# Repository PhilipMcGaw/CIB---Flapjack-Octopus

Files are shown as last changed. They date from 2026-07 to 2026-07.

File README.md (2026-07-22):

# CIB - Flapjack Octopus
<div align="center">




<!-- removed as not used in this repo ![Fusion 360](https://badgen.net/badge/icon/FUSION%20360?icon=autodesk&label) -->

</div>

| By Ed Bowlby, NOAA/Olympic Coast NMS; NOAA/OAR/Office of Ocean Exploration - NOAA Photo Library, Public Domain (https://commons.wikimedia.org/w/index.php?curid=11244142) | Breakout board for Labjack T7 |
| --- |:---:|

Breakout board for Labjack T7

### Flapjack Octopus -- Labjack T7 Breakout

This is a breakout PCB for a Labjack T7, with 2.5 mm pitch screw headers to allow for quick wiring to the breakout PCB.

  * Digital IO ports are 5 V tolerant, there is no additional protection on the PCB.
  * Digital IO on ports C, E, F and M each have an LED that illuminates when 5V DC is applied
  * Digital IO port F is also set up as eight relay outputs, allowing up to eight 12/24 V (separate power supply required) to be driven from the T7 Labjack
  * Analogue in ports are taken via a potential divider to allow pre-scaling if required.
  * Additional terminals are available for 5V and Ground, as well as other pins, these are on the lower edge.

# Sub Modules

github.com/PhilipMcGaw/common_kicad

git submodule add https://github.com/PhilipMcGaw/common_kicad KiCAD/Common

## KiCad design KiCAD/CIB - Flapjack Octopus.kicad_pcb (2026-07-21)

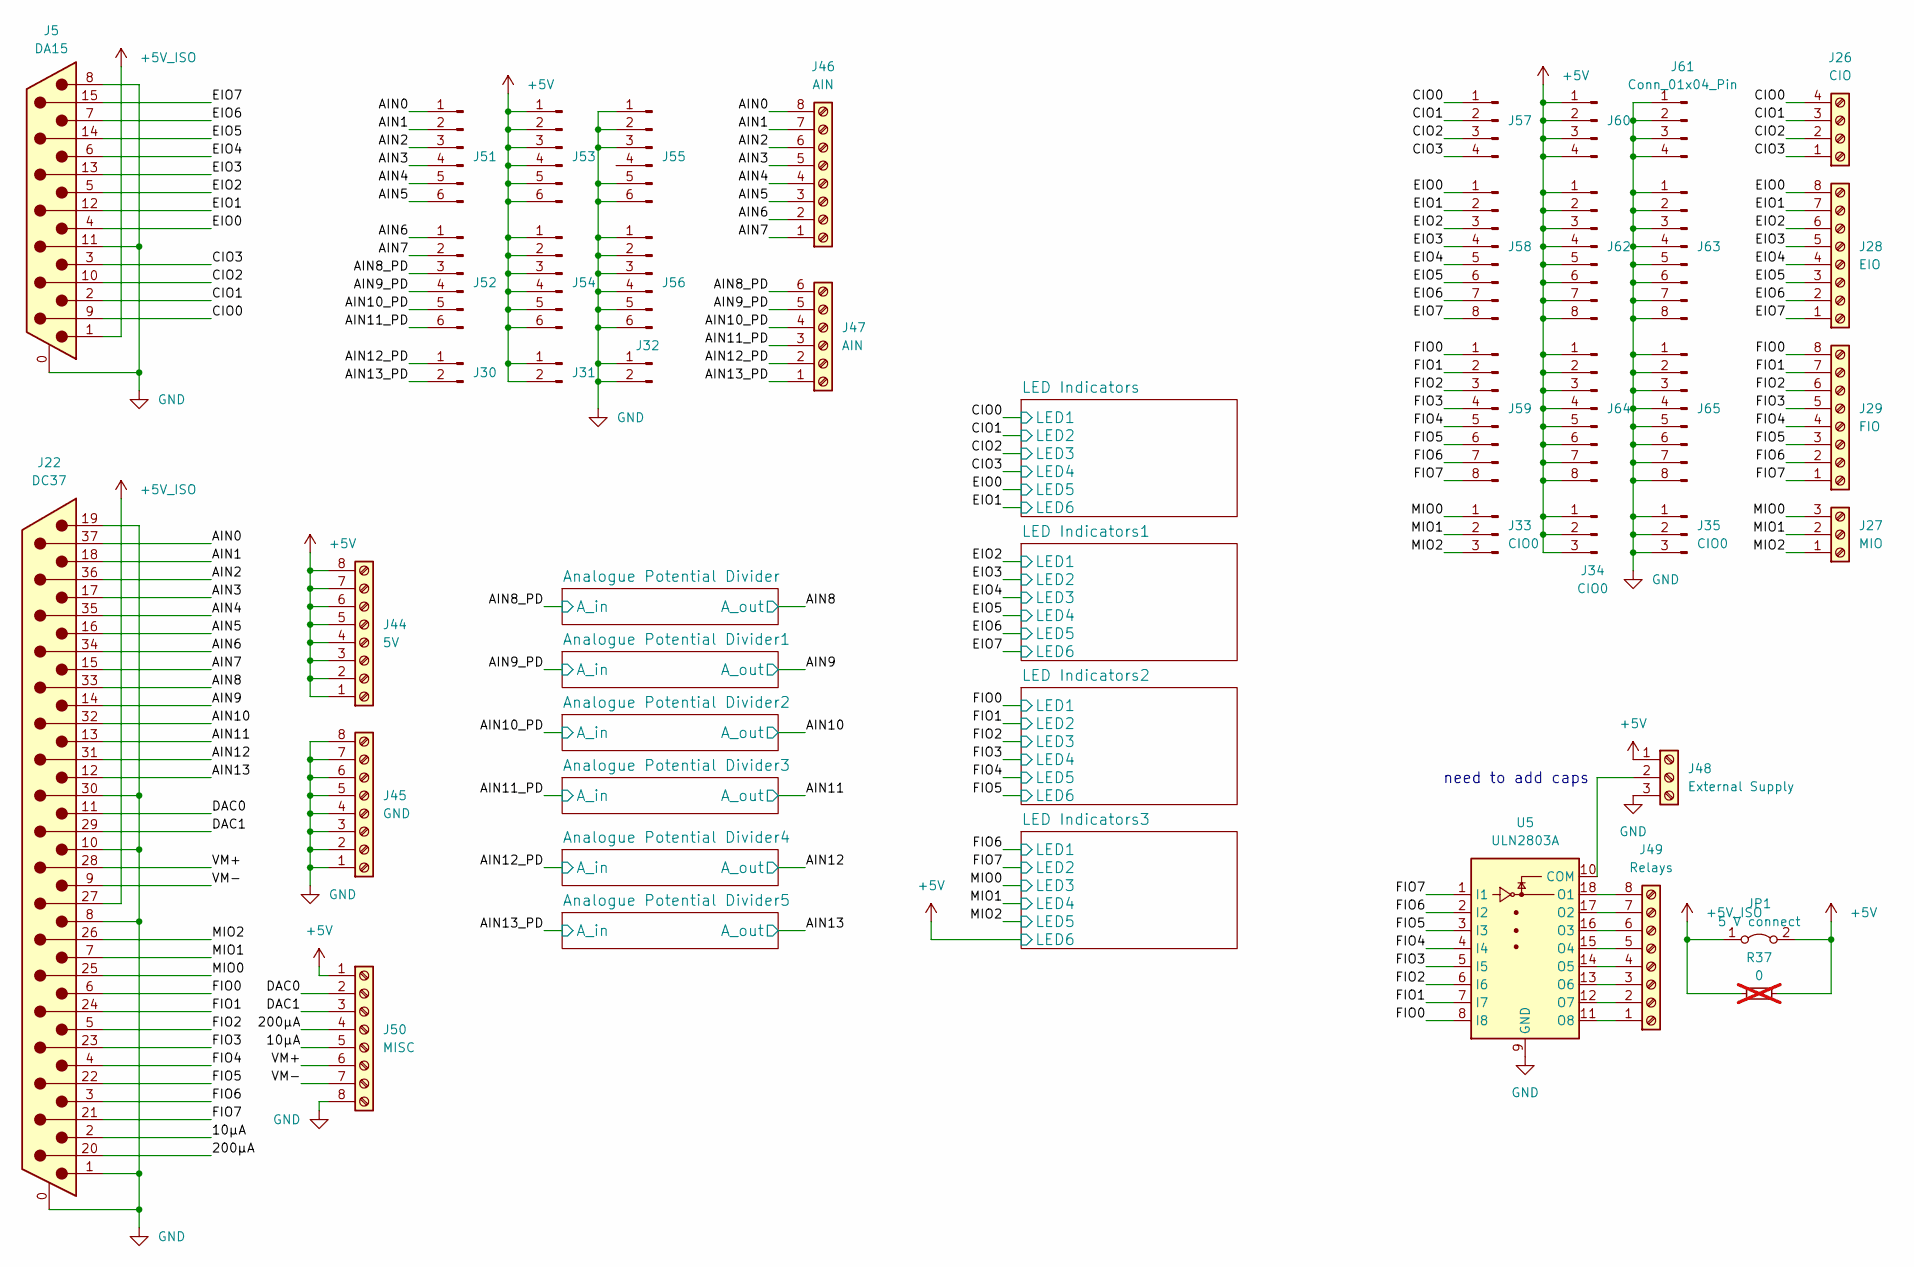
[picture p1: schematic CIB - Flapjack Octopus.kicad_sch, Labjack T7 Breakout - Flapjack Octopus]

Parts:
J5: DA15; DSUB-15_Male_Horizontal_P2.77x2.84mm_EdgePinOffset9.90mm_Ho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
J22: DC37; DSUB-37_Male_Horizontal_P2.77x2.84mm_EdgePinOffset7.70mm_Ho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
J26: CIO; TerminalBlock_Phoenix_MPT-0,5-4-2.54_1x04_P2.54mm_Horizontal
J27: MIO; TerminalBlock_Phoenix_MPT-0,5-3-2.54_1x03_P2.54mm_Horizontal
J28: EIO; TerminalBlock_Phoenix_MPT-0,5-8-2.54_1x08_P2.54mm_Horizontal
J29: FIO; TerminalBlock_Phoenix_MPT-0,5-8-2.54_1x08_P2.54mm_Horizontal
J30, J31, J32: Conn_01x02_Pin; PinSocket_1x02_P2.54mm_Vertical
J33, J34, J35: CIO0; PinSocket_1x03_P2.54mm_Vertical
J44: 5V; TerminalBlock_Phoenix_MPT-0,5-8-2.54_1x08_P2.54mm_Horizontal
J45: GND; TerminalBlock_Phoenix_MPT-0,5-8-2.54_1x08_P2.54mm_Horizontal
J46: AIN; TerminalBlock_Phoenix_MPT-0,5-8-2.54_1x08_P2.54mm_Horizontal
J47: AIN; TerminalBlock_Phoenix_MPT-0,5-6-2.54_1x06_P2.54mm_Horizontal
J48: External Supply; TerminalBlock_Phoenix_MPT-0,5-3-2.54_1x03_P2.54mm_Horizontal
J49: Relays; TerminalBlock_Phoenix_MPT-0,5-8-2.54_1x08_P2.54mm_Horizontal
J50: MISC; TerminalBlock_Phoenix_MPT-0,5-8-2.54_1x08_P2.54mm_Horizontal
J51, J52, J53, J54, J55, J56: Conn_01x06_Pin; PinHeader_1x06_P2.54mm_Vertical
J57, J60, J61: Conn_01x04_Pin; PinHeader_1x04_P2.54mm_Vertical
J58, J59, J62, J63, J64, J65: Conn_01x08_Pin; PinHeader_1x08_P2.54mm_Vertical
JP1: 5 V connect; SolderJumper-2_P1.3mm_Bridged_Pad1.0x1.5mm
R37: 0; R_0805_2012Metric_Pad1.20x1.40mm_HandSolder; not fitted
U5: ULN2803A; SOIC-18W_7.5x11.6mm_P1.27mm

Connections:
+5V: J31.1, J31.2, J34.1, J34.2, J34.3, J44.1, J44.2, J44.3, J44.4, J44.5, J44.6, J44.7, J44.8, J48.1, J50.1, J53.1, J53.2, J53.3, J53.4, J53.5, J53.6, J54.1, J54.2, J54.3, J54.4, J54.5, J54.6, J60.1, J60.2, J60.3, J60.4, J62.1, J62.2, J62.3, J62.4, J62.5, J62.6, J62.7, J62.8, J64.1, J64.2, J64.3, J64.4, J64.5, J64.6, J64.7, J64.8, JP1.2 (B), R37.2; also elsewhere on the board
+5V_ISO: J5.1, J22.27, JP1.1 (A), R37.1
/10µA: J22.2, J50.5
/200µA: J22.20, J50.4
/AIN0: J22.37, J46.8, J51.1
/AIN1: J22.18, J46.7, J51.2
/AIN2: J22.36, J46.6, J51.3
/AIN3: J22.17, J46.5, J51.4
/AIN4: J22.35, J46.4, J51.5
/AIN5: J22.16, J46.3, J51.6
/AIN6: J22.34, J46.2, J52.1
/AIN7: J22.15, J46.1, J52.2
/AIN8: J22.33; also elsewhere on the board
/AIN8_PD: J47.6, J52.3; also elsewhere on the board
/AIN9: J22.14; also elsewhere on the board
/AIN9_PD: J47.5, J52.4; also elsewhere on the board
/AIN10: J22.32; also elsewhere on the board
/AIN10_PD: J47.4, J52.5; also elsewhere on the board
/AIN11: J22.13; also elsewhere on the board
/AIN11_PD: J47.3, J52.6; also elsewhere on the board
/AIN12: J22.31; also elsewhere on the board
/AIN12_PD: J30.1, J47.2; also elsewhere on the board
/AIN13: J22.12; also elsewhere on the board
/AIN13_PD: J30.2, J47.1; also elsewhere on the board
/CIO0: J5.9, J26.4, J57.1; also elsewhere on the board
/CIO1: J5.2, J26.3, J57.2; also elsewhere on the board
/CIO2: J5.10, J26.2, J57.3; also elsewhere on the board
/CIO3: J5.3, J26.1, J57.4; also elsewhere on the board
/DAC0: J22.11, J50.2
/DAC1: J22.29, J50.3
/EIO0: J5.4, J28.8, J58.1; also elsewhere on the board
/EIO1: J5.12, J28.7, J58.2; also elsewhere on the board
/EIO2: J5.5, J28.6, J58.3; also elsewhere on the board
/EIO3: J5.13, J28.5, J58.4; also elsewhere on the board
/EIO4: J5.6, J28.4, J58.5; also elsewhere on the board
/EIO5: J5.14, J28.3, J58.6; also elsewhere on the board
/EIO6: J5.7, J28.2, J58.7; also elsewhere on the board
/EIO7: J5.15, J28.1, J58.8; also elsewhere on the board
/FIO0: J22.6, J29.8, J59.1, U5.8 (I8); also elsewhere on the board
/FIO1: J22.24, J29.7, J59.2, U5.7 (I7); also elsewhere on the board
/FIO2: J22.5, J29.6, J59.3, U5.6 (I6); also elsewhere on the board
/FIO3: J22.23, J29.5, J59.4, U5.5 (I5); also elsewhere on the board
/FIO4: J22.4, J29.4, J59.5, U5.4 (I4); also elsewhere on the board
/FIO5: J22.22, J29.3, J59.6, U5.3 (I3); also elsewhere on the board
/FIO6: J22.3, J29.2, J59.7, U5.2 (I2); also elsewhere on the board
/FIO7: J22.21, J29.1, J59.8, U5.1 (I1); also elsewhere on the board
/MIO0: J22.25, J27.3, J33.1; also elsewhere on the board
/MIO1: J22.7, J27.2, J33.2; also elsewhere on the board
/MIO2: J22.26, J27.1, J33.3; also elsewhere on the board
/VM+: J22.28, J50.6
/VM-: J22.9, J50.7
GND: J5.0 (PAD), J5.8, J5.11 (P111), J22.0 (PAD), J22.1, J22.8, J22.10, J22.19, J22.30, J32.1, J32.2, J35.1, J35.2, J35.3, J45.1, J45.2, J45.3, J45.4, J45.5, J45.6, J45.7, J45.8, J48.3, J50.8, J55.1, J55.2, J55.3, J55.5, J55.6, J56.1, J56.2, J56.3, J56.4, J56.5, J56.6, J61.1, J61.2, J61.3, J61.4, J63.1, J63.2, J63.3, J63.4, J63.5, J63.6, J63.7, J63.8, J65.1, J65.2, J65.3, J65.4, J65.5, J65.6, J65.7, J65.8, U5.9 (GND); also elsewhere on the board
unnamed: J48.2, U5.10 (COM)
unnamed: J49.1, U5.11 (O8)
unnamed: J49.2, U5.12 (O7)
unnamed: J49.3, U5.13 (O6)
unnamed: J49.4, U5.14 (O5)
unnamed: J49.5, U5.15 (O4)
unnamed: J49.6, U5.16 (O3)
unnamed: J49.7, U5.17 (O2)
unnamed: J49.8, U5.18 (O1)

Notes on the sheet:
need to add caps

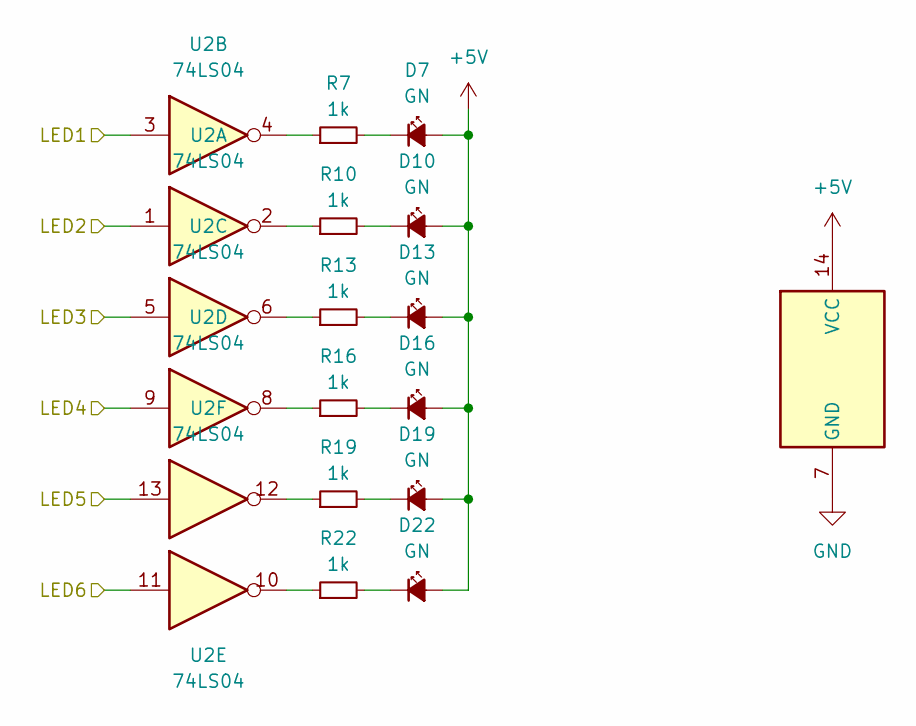
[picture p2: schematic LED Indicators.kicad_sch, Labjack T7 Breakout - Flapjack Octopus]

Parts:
D7, D10, D13, D16, D19, D22: GN; LED_0805_2012Metric_Pad1.15x1.40mm_HandSolder
R7, R10, R13, R16, R19, R22: 1k; R_0805_2012Metric_Pad1.20x1.40mm_HandSolder
U2, U4: 74LS04

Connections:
+5V: D7.2 (A), D10.2 (A), D13.2 (A), D16.2 (A), D19.2 (A), D22.2 (A), U4.14 (VCC); also elsewhere on the board
/CIO0: U2.3; also elsewhere on the board
/CIO1: U2.1; also elsewhere on the board
/CIO2: U2.5; also elsewhere on the board
/CIO3: U2.9; also elsewhere on the board
/EIO0: U2.13; also elsewhere on the board
/EIO1: U2.11; also elsewhere on the board
/FIO0: U4.3; also elsewhere on the board
/FIO1: U4.1; also elsewhere on the board
/FIO2: U4.5; also elsewhere on the board
/FIO3: U4.9; also elsewhere on the board
/FIO4: U4.13; also elsewhere on the board
/FIO5: U4.11; also elsewhere on the board
GND: U4.7 (GND); also elsewhere on the board
unnamed: D7.1 (K), R7.2
unnamed: D10.1 (K), R10.2
unnamed: D13.1 (K), R13.2
unnamed: D16.1 (K), R16.2
unnamed: D19.1 (K), R19.2
unnamed: D22.1 (K), R22.2
unnamed: R7.1, U2.4
unnamed 93: U4.4; also elsewhere on the board
unnamed: R10.1, U2.2
unnamed 96: U4.2; also elsewhere on the board
unnamed: R13.1, U2.6
unnamed 99: U4.6; also elsewhere on the board
unnamed: R16.1, U2.8
unnamed 102: U4.8; also elsewhere on the board
unnamed: R19.1, U2.12
unnamed 105: U4.12; also elsewhere on the board
unnamed: R22.1, U2.10
unnamed 108: U4.10; also elsewhere on the board

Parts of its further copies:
D8, D9, D11, D12, D14, D15, D17, D18, D20, D21, D23, D24, D25, D26, D27, D28, D29, D30: GN; LED_0805_2012Metric_Pad1.15x1.40mm_HandSolder
R8, R9, R11, R12, R14, R15, R17, R18, R20, R21, R23, R24, R25, R26, R27, R28, R29, R30: 1k; R_0805_2012Metric_Pad1.20x1.40mm_HandSolder
U3, U6: 74LS04

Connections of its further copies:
+5V: D8.2 (A), D9.2 (A), D11.2 (A), D12.2 (A), D14.2 (A), D15.2 (A), D17.2 (A), D18.2 (A), D20.2 (A), D21.2 (A), D23.2 (A), D24.2 (A), D25.2 (A), D26.2 (A), D27.2 (A), D28.2 (A), D29.2 (A), D30.2 (A), U6.11, U6.14 (VCC); also elsewhere on the board
/EIO2: U3.3; also elsewhere on the board
/EIO3: U3.1; also elsewhere on the board
/EIO4: U3.5; also elsewhere on the board
/EIO5: U3.9; also elsewhere on the board
/EIO6: U3.13; also elsewhere on the board
/EIO7: U3.11; also elsewhere on the board
/FIO6: U6.3; also elsewhere on the board
/FIO7: U6.1; also elsewhere on the board
/MIO0: U6.5; also elsewhere on the board
/MIO1: U6.9; also elsewhere on the board
/MIO2: U6.13; also elsewhere on the board
GND: U6.7 (GND); also elsewhere on the board
unnamed: D8.1 (K), R8.2
unnamed: D9.1 (K), R9.2
unnamed: D11.1 (K), R11.2
unnamed: D12.1 (K), R12.2
unnamed: D14.1 (K), R14.2
unnamed: D15.1 (K), R15.2
unnamed: D17.1 (K), R17.2
unnamed: D18.1 (K), R18.2
unnamed: D20.1 (K), R20.2
unnamed: D21.1 (K), R21.2
unnamed: D23.1 (K), R23.2
unnamed: D24.1 (K), R24.2
unnamed: D25.1 (K), R25.2
unnamed: D26.1 (K), R26.2
unnamed: D27.1 (K), R27.2
unnamed: D28.1 (K), R28.2
unnamed: D29.1 (K), R29.2
unnamed: D30.1 (K), R30.2
unnamed: R8.1, U3.4
unnamed 93: R9.1; also elsewhere on the board
unnamed: R11.1, U3.2
unnamed 96: R12.1; also elsewhere on the board
unnamed: R14.1, U3.6
unnamed 99: R15.1; also elsewhere on the board
unnamed: R17.1, U3.8
unnamed 102: R18.1; also elsewhere on the board
unnamed: R20.1, U3.12
unnamed 105: R21.1; also elsewhere on the board
unnamed: R23.1, U3.10
unnamed 108: R24.1; also elsewhere on the board
unnamed: R25.1, U6.4
unnamed: R26.1, U6.2
unnamed: R27.1, U6.6
unnamed: R28.1, U6.8
unnamed: R29.1, U6.12
unnamed: R30.1, U6.10

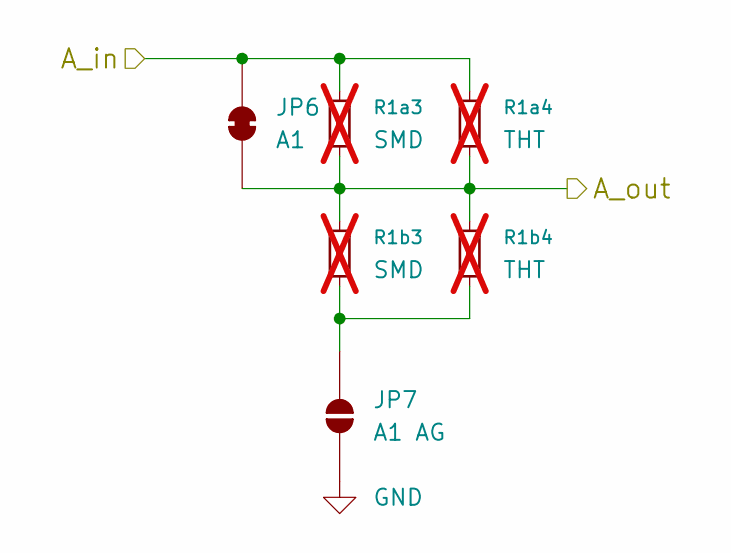
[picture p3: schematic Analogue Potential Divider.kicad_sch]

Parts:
JP6: A1; SolderJumper-2_P1.3mm_Bridged_RoundedPad1.0x1.5mm
JP7: A1 AG; SolderJumper-2_P1.3mm_Open_RoundedPad1.0x1.5mm
R1a3, R1b3: SMD; R_0805_2012Metric_Pad1.20x1.40mm_HandSolder; not fitted
R1a4, R1b4: THT; R_Axial_DIN0207_L6.3mm_D2.5mm_P10.16mm_Horizontal; not fitted

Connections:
/AIN8: JP6.1 (A), R1a3.2, R1a4.2, R1b3.1, R1b4.1; also elsewhere on the board
/AIN8_PD: JP6.2 (B), R1a3.1, R1a4.1; also elsewhere on the board
GND: JP7.1 (A); also elsewhere on the board
unnamed: JP7.2 (B), R1b3.2, R1b4.2

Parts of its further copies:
JP8, JP10, JP12, JP14, JP16: A1; SolderJumper-2_P1.3mm_Bridged_RoundedPad1.0x1.5mm
JP9, JP11, JP13, JP15, JP17: A1 AG; SolderJumper-2_P1.3mm_Open_RoundedPad1.0x1.5mm
R1a5, R1a7, R1a9, R1a11, R1a13, R1b5, R1b7, R1b9, R1b11, R1b13: SMD; R_0805_2012Metric_Pad1.20x1.40mm_HandSolder; not fitted
R1a6, R1a8, R1a10, R1a12, R1a14, R1b6, R1b8, R1b10, R1b12, R1b14: THT; R_Axial_DIN0207_L6.3mm_D2.5mm_P10.16mm_Horizontal; not fitted

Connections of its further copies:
/AIN9: JP8.1 (A), R1a5.2, R1a6.2, R1b5.1, R1b6.1; also elsewhere on the board
/AIN9_PD: JP8.2 (B), R1a5.1, R1a6.1; also elsewhere on the board
/AIN10: JP10.1 (A), R1a7.2, R1a8.2, R1b7.1, R1b8.1; also elsewhere on the board
/AIN10_PD: JP10.2 (B), R1a7.1, R1a8.1; also elsewhere on the board
/AIN11: JP12.1 (A), R1a9.2, R1a10.2, R1b9.1, R1b10.1; also elsewhere on the board
/AIN11_PD: JP12.2 (B), R1a9.1, R1a10.1; also elsewhere on the board
/AIN12: JP14.1 (A), R1a11.2, R1a12.2, R1b11.1, R1b12.1; also elsewhere on the board
/AIN12_PD: JP14.2 (B), R1a11.1, R1a12.1; also elsewhere on the board
/AIN13: JP16.1 (A), R1a13.2, R1a14.2, R1b13.1, R1b14.1; also elsewhere on the board
/AIN13_PD: JP16.2 (B), R1a13.1, R1a14.1; also elsewhere on the board
GND: JP9.1 (A), JP11.1 (A), JP13.1 (A), JP15.1 (A), JP17.1 (A); also elsewhere on the board
unnamed: JP9.2 (B), R1b5.2, R1b6.2
unnamed: JP11.2 (B), R1b7.2, R1b8.2
unnamed: JP13.2 (B), R1b9.2, R1b10.2
unnamed: JP15.2 (B), R1b11.2, R1b12.2
unnamed: JP17.2 (B), R1b13.2, R1b14.2

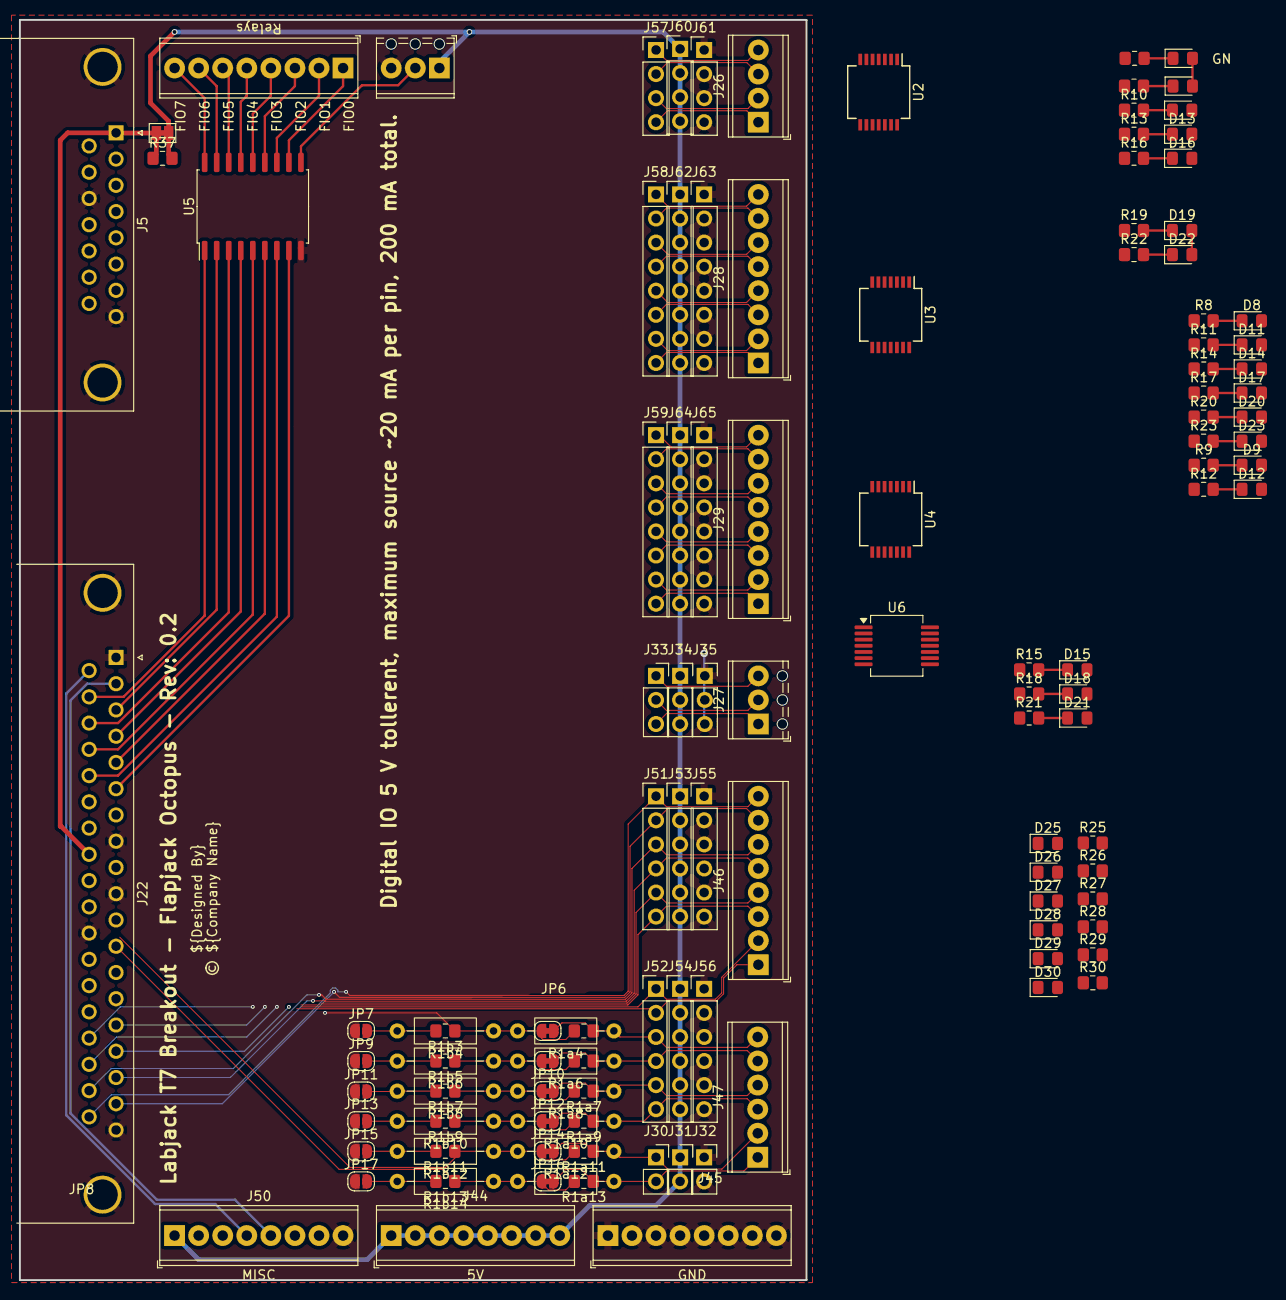
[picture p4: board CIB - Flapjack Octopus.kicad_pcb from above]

Board: 2 copper layers, 83.0 x 133.0 mm, 125 parts (0 on the bottom side), 115 nets.

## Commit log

2026-07-22 Update README by removing description and badge
    Removed project description and KiCad badge from README.
2026-07-22 remove common files… this may be an error
    [LED - CXA1304.step, MS5803-14BA.step, PGA2350.step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]

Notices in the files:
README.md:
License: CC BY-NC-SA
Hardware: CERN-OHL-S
